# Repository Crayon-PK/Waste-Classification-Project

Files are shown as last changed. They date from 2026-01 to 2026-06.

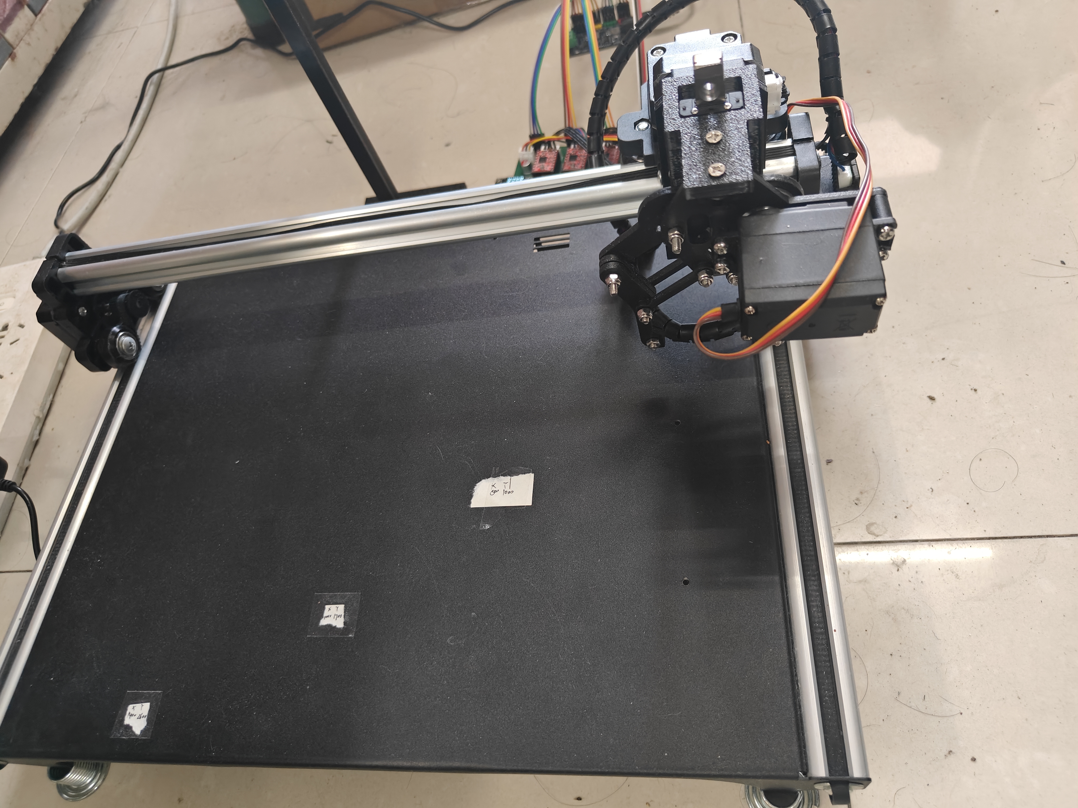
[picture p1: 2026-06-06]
picture/IMG20260606160438.jpg

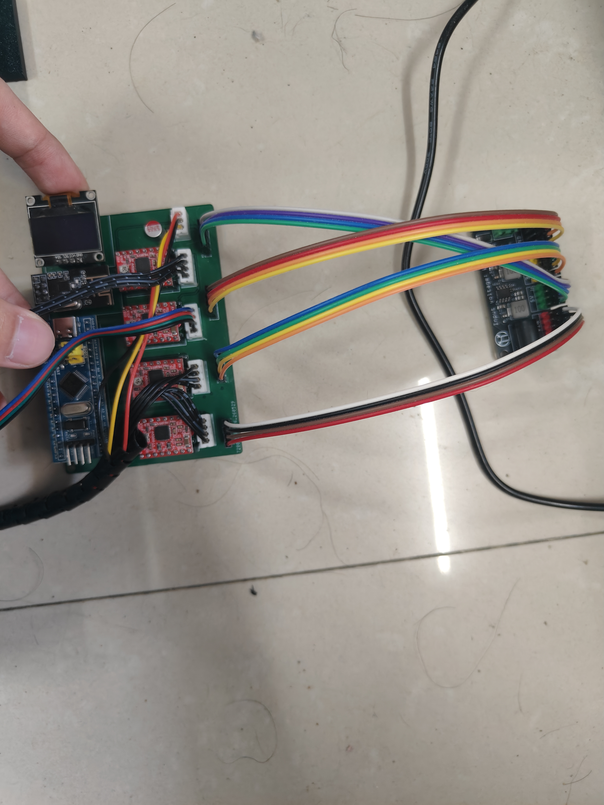
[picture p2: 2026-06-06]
picture/IMG20260606161021.jpg

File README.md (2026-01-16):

\# 智能垃圾分类系统 (Smart Waste Classification System)

本项目包含从机械结构、电路设计、嵌入式固件到上位机代码。

\## 📂 目录结构说明

\* \*\*Software\*\*: 上位机代码 (Python + YOLOv5-Lite)，负责视觉识别与串口通讯。

\* \*\*Firmware\*\*: 下位机固件 (STM32F103 + FreeRTOS)，负责处理上位机信息，控制步进电机、舵机与 OLED日志打印。

\* \*\*Hardware\*\*: PCB 工程文件 (立创EDA专业版格式)。

\* \*\*Mechanical\*\*: 3D 机械结构设计 (SolidWorks 源文件 + 打印用 STL)。

\## 🚀 快速上手

\### 1. 软件端 (Software)

\* \*\*环境\*\*: Python 3.8+, 安装依赖: `pip install -r Software/requirements.txt`

\* \*\*运行\*\*: 

&nbsp;   1. 连接 USB 摄像头和串口工具。

&nbsp;   2. 进入目录: `cd Software`

&nbsp;   3. 运行主程序: `python gui.py`

\* \*\*注意\*\*: 权重文件已包含在 `Software/weights/best2.pt`，无需额外下载。

\### 2. 固件端 (Firmware)

\* \*\*环境\*\*: Keil uVision 5 (MDK-ARM).

\* \*\*编译\*\*: 打开 `Firmware/MDK-ARM/Project.uvprojx`，点击 "Rebuild" 即可重新生成 Hex 文件。

\* \*\*烧录\*\*: 使用 ST-Link Utility 或 Keil 直接下载。

\### 3. 硬件与机械

\* \*\*PCB\*\*: 使用立创EDA专业版打开 `Hardware/PCB.eprj2`。

\* \*\*3D\*\*: 使用 SolidWorks 2020 或更高版本打开 `Mechanical` 文件夹内的 `.SLDASM` 装配体。

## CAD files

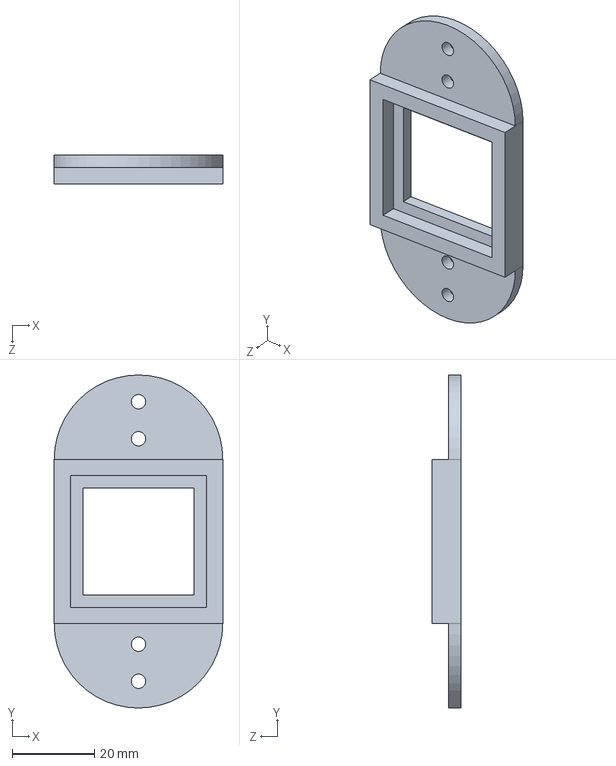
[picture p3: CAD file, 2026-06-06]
Mechanical/摄像头固定模块.SLDPRT
41.0 x 81.0 x 7.00 mm

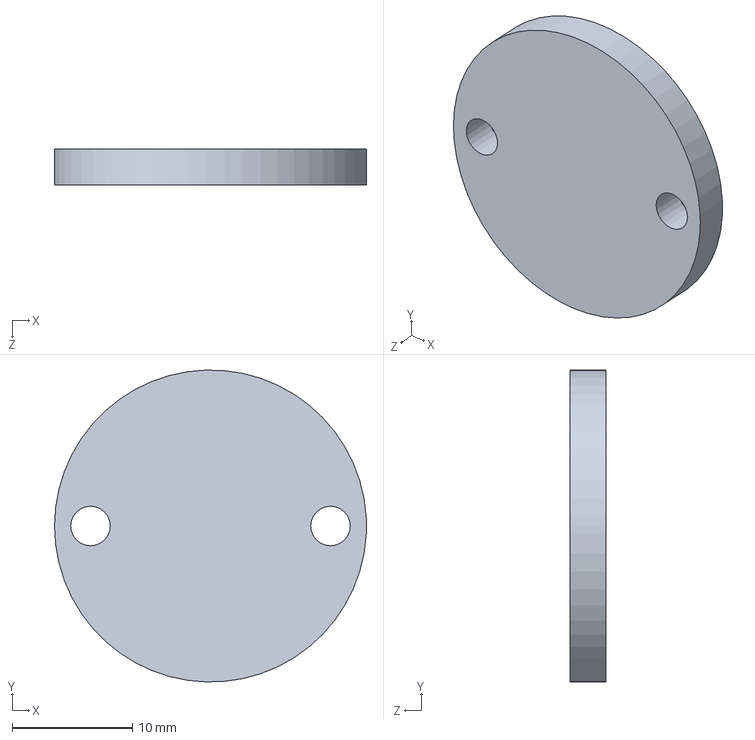
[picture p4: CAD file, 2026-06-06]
Mechanical/传动轴.SLDPRT
26.0 x 26.0 x 3.00 mm

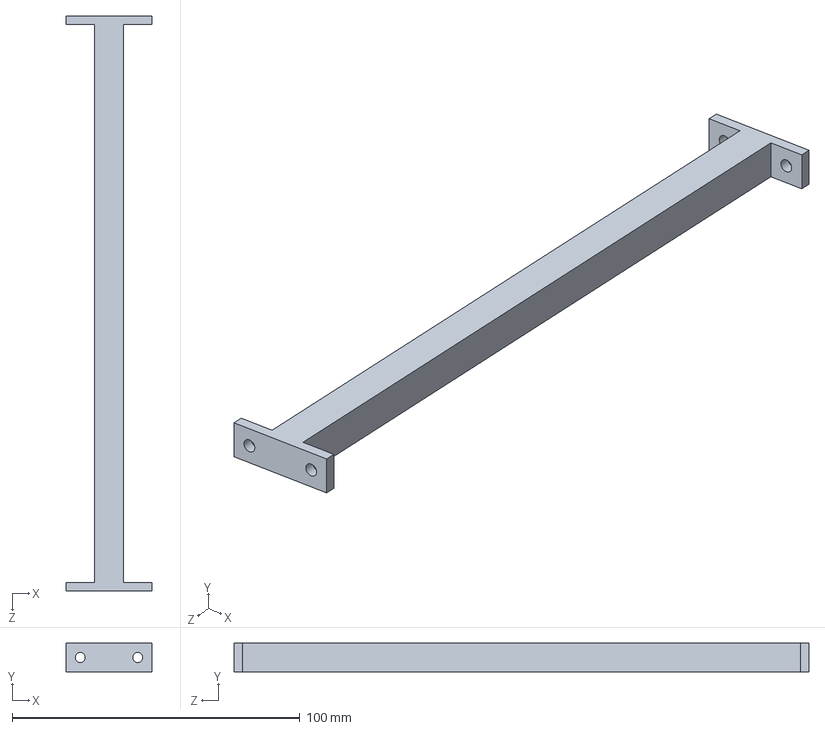
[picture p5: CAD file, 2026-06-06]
Mechanical/高度支架.SLDPRT
30.0 x 10.0 x 200.0 mm

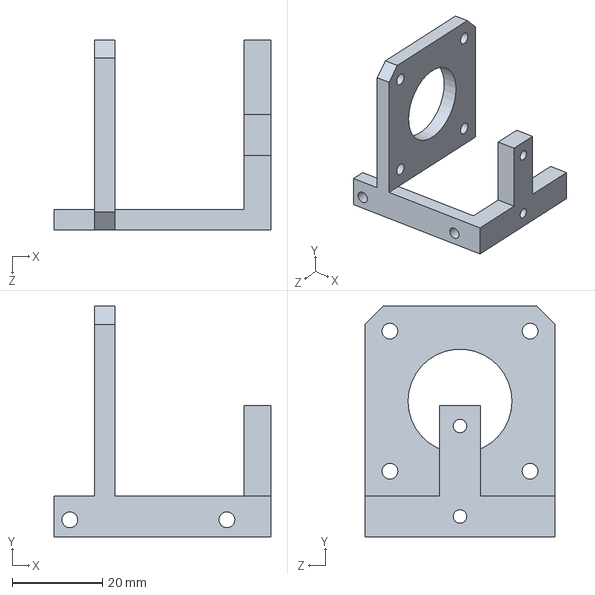
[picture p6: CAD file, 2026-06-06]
Mechanical/固定模块.SLDPRT
48.0 x 51.0 x 42.0 mm

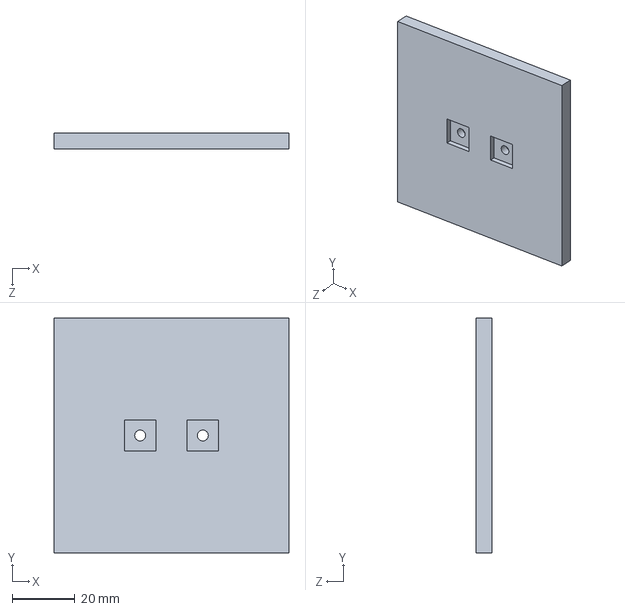
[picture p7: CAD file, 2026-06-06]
Mechanical/高度支架地基.SLDPRT
75.0 x 75.0 x 5.00 mm

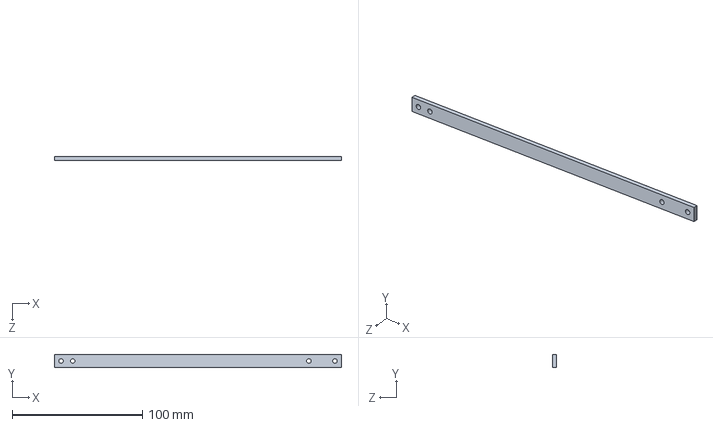
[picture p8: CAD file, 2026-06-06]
Mechanical/摄像头横向支架.SLDPRT
220.0 x 10.0 x 3.00 mm

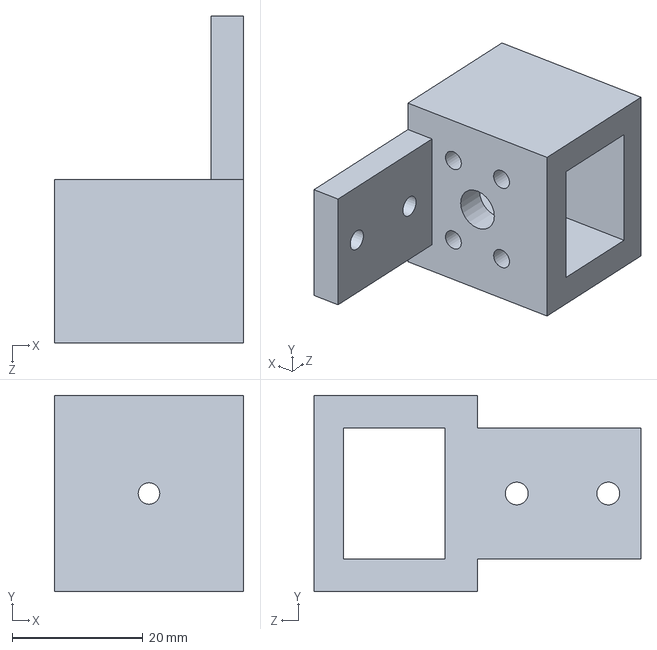
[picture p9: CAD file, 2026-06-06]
Mechanical/滑块夹爪固定装置.SLDPRT
28.9 x 30.0 x 50.0 mm

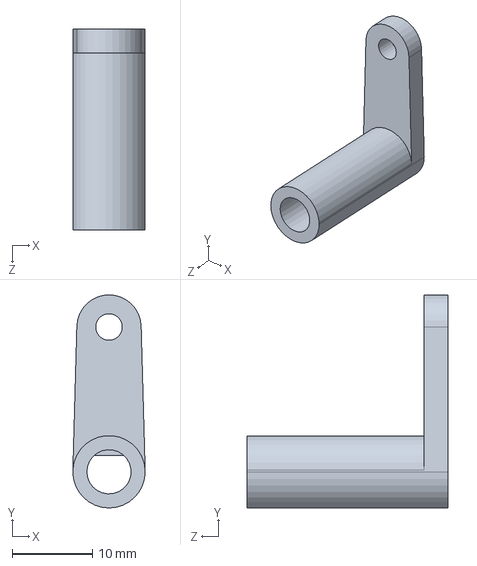
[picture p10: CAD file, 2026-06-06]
Mechanical/主动轴.SLDPRT
9.00 x 26.5 x 25.0 mm

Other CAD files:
Mechanical/STL/主动轴.STL
Mechanical/STL/传动轴.STL
Mechanical/STL/固定模块.STL
Mechanical/STL/摄像头固定模块.STL
Mechanical/STL/摄像头横向支架.STL
Mechanical/STL/滑块夹爪固定装置.STL
Mechanical/STL/高度支架.STL
Mechanical/STL/高度支架地基.STL

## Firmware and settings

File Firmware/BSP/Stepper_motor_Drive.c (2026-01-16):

#include "stm32f10x.h"
#include <stddef.h>

//================== 电机引脚定义 ==================
#define MOTOR_X_GPIO_PORT      GPIOB
#define MOTOR_X_STEP_PIN       GPIO_Pin_0     // PB0 - TIM3_CH3
#define MOTOR_X1_DIR_PIN       GPIO_Pin_12
#define MOTOR_X2_DIR_PIN       GPIO_Pin_13
#define MOTOR_X_EN_PIN         GPIO_Pin_14

#define MOTOR_Y_GPIO_PORT      GPIOA
#define MOTOR_Y_STEP_PIN       GPIO_Pin_3     // PA3 - TIM2_CH4
#define MOTOR_Y_DIR_PIN        GPIO_Pin_4
#define MOTOR_Y_EN_PIN         GPIO_Pin_5

#define MOTOR_Z_GPIO_PORT      GPIOB
#define MOTOR_Z_STEP_PIN       GPIO_Pin_9     // PB9 - TIM4_CH4
#define MOTOR_Z_DIR_PIN        GPIO_Pin_8
#define MOTOR_Z_EN_PIN         GPIO_Pin_5

//================ 电机相关参数 ==================
#define MOTOR_X 0
#define MOTOR_Y 1
#define MOTOR_Z 2

#define PWM_ARR 999
#define PWM_PSC 71

#define M_ENABLE  1
#define M_DISABLE 0

//================ 全局变量 ==================
volatile int32_t motor_pos_x = 0;
volatile int32_t motor_pos_y = 0;
volatile int32_t motor_pos_z = 0;

static volatile uint32_t step_count_x = 0, target_steps_x = 0;
static volatile uint32_t step_count_y = 0, target_steps_y = 0;
static volatile uint32_t step_count_z = 0, target_steps_z = 0;

static volatile uint8_t dir_x = 1, dir_y = 1, dir_z = 1;

typedef void (*Stepper_Callback_t)(uint8_t motor_id);
static Stepper_Callback_t cb_x = NULL;
static Stepper_Callback_t cb_y = NULL;
static Stepper_Callback_t cb_z = NULL;

void Stepper_RegisterCallback(uint8_t MotorID, Stepper_Callback_t cb)
{
    switch (MotorID)
    {
        case MOTOR_X: cb_x = cb; break;
        case MOTOR_Y: cb_y = cb; break;
        case MOTOR_Z: cb_z = cb; break;
    }
}
//-----------------------------------------------------------------GPIO引脚初始化-----------------------------------------------------------------
static void Motor_X_GPIO_Init(void)
{
    GPIO_InitTypeDef GPIO_InitStructure;

    RCC_APB2PeriphClockCmd(RCC_APB2Periph_GPIOB | RCC_APB2Periph_AFIO, ENABLE);

    // DIR & EN
    GPIO_InitStructure.GPIO_Pin = MOTOR_X1_DIR_PIN | MOTOR_X2_DIR_PIN | MOTOR_X_EN_PIN;
    GPIO_InitStructure.GPIO_Mode = GPIO_Mode_Out_PP;
    GPIO_InitStructure.GPIO_Speed = GPIO_Speed_50MHz;
    GPIO_Init(MOTOR_X_GPIO_PORT, &GPIO_InitStructure);

    // STEP (PWM output)
    GPIO_InitStructure.GPIO_Pin = MOTOR_X_STEP_PIN;
    GPIO_InitStructure.GPIO_Mode = GPIO_Mode_AF_PP;
    GPIO_Init(MOTOR_X_GPIO_PORT, &GPIO_InitStructure);

    // 默认状态：EN=高（禁用）
    GPIO_SetBits(MOTOR_X_GPIO_PORT, MOTOR_X_EN_PIN);
    GPIO_ResetBits(MOTOR_X_GPIO_PORT, MOTOR_X1_DIR_PIN);
    GPIO_SetBits(MOTOR_X_GPIO_PORT, MOTOR_X2_DIR_PIN);
}

static void Motor_Y_GPIO_Init(void)
{
    GPIO_InitTypeDef GPIO_InitStructure;

    RCC_APB2PeriphClockCmd(RCC_APB2Periph_GPIOA | RCC_APB2Periph_AFIO, ENABLE);

    // DIR & EN
    GPIO_InitStructure.GPIO_Pin = MOTOR_Y_DIR_PIN | MOTOR_Y_EN_PIN;
    GPIO_InitStructure.GPIO_Mode = GPIO_Mode_Out_PP;
    GPIO_InitStructure.GPIO_Speed = GPIO_Speed_50MHz;
    GPIO_Init(MOTOR_Y_GPIO_PORT, &GPIO_InitStructure);

    // STEP (PWM output)
    GPIO_InitStructure.GPIO_Pin = MOTOR_Y_STEP_PIN; // PA3 TIM2_CH4
    GPIO_InitStructure.GPIO_Mode = GPIO_Mode_AF_PP;
    GPIO_Init(MOTOR_Y_GPIO_PORT, &GPIO_InitStructure);

    GPIO_SetBits(MOTOR_Y_GPIO_PORT, MOTOR_Y_EN_PIN);
    GPIO_ResetBits(MOTOR_Y_GPIO_PORT, MOTOR_Y_DIR_PIN);
}

static void Motor_Z_GPIO_Init(void)
{
    GPIO_InitTypeDef GPIO_InitStructure;

    RCC_APB2PeriphClockCmd(RCC_APB2Periph_GPIOB | RCC_APB2Periph_AFIO, ENABLE);

    // DIR & EN
    GPIO_InitStructure.GPIO_Pin = MOTOR_Z_DIR_PIN | MOTOR_Z_EN_PIN;
    GPIO_InitStructure.GPIO_Mode = GPIO_Mode_Out_PP;
    GPIO_InitStructure.GPIO_Speed = GPIO_Speed_50MHz;
    GPIO_Init(MOTOR_Z_GPIO_PORT, &GPIO_InitStructure);

    // STEP (PWM output)
    GPIO_InitStructure.GPIO_Pin = MOTOR_Z_STEP_PIN;
    GPIO_InitStructure.GPIO_Mode = GPIO_Mode_AF_PP;
    GPIO_Init(MOTOR_Z_GPIO_PORT, &GPIO_InitStructure);

    GPIO_SetBits(MOTOR_Z_GPIO_PORT, MOTOR_Z_EN_PIN);
    GPIO_ResetBits(MOTOR_Z_GPIO_PORT, MOTOR_Z_DIR_PIN);
}

//-----------------------------------------------------------------PWM初始化-----------------------------------------------------------------
static void PWM_ChannelInit(TIM_TypeDef* TIMx, uint8_t channel, uint32_t arr, uint32_t psc)
{
    TIM_TimeBaseInitTypeDef TIM_TimeBaseStructure;
    TIM_OCInitTypeDef TIM_OCInitStructure;

    // 时基
    TIM_TimeBaseStructure.TIM_Period = (arr == 0) ? 1 : (arr - 1);
    TIM_TimeBaseStructure.TIM_Prescaler = (psc == 0) ? 0 : (psc - 1);
    TIM_TimeBaseStructure.TIM_ClockDivision = 0;
    TIM_TimeBaseStructure.TIM_CounterMode = TIM_CounterMode_Up;
    TIM_TimeBaseInit(TIMx, &TIM_TimeBaseStructure);

    // PWM 输出配置
    TIM_OCInitStructure.TIM_OCMode = TIM_OCMode_PWM1;
    TIM_OCInitStructure.TIM_OutputState = TIM_OutputState_Enable;
    TIM_OCInitStructure.TIM_Pulse = (TIMx->ARR + 1) / 2; // 默认 50% 占空比
    TIM_OCInitStructure.TIM_OCPolarity = TIM_OCPolarity_High;

    if (TIMx == TIM3 && channel == 3) {
        TIM_OC3Init(TIMx, &TIM_OCInitStructure);
        TIM_OC3PreloadConfig(TIMx, TIM_OCPreload_Enable);
    } else if (TIMx == TIM2 && channel == 4) {
        TIM_OC4Init(TIMx, &TIM_OCInitStructure);
        TIM_OC4PreloadConfig(TIMx, TIM_OCPreload_Enable);
    } else if (TIMx == TIM4 && channel == 4) {
        TIM_OC4Init(TIMx, &TIM_OCInitStructure);
        TIM_OC4PreloadConfig(TIMx, TIM_OCPreload_Enable);
    }

    TIM_ARRPreloadConfig(TIMx, ENABLE);
    // TIM_Cmd(TIMx, ENABLE); // 不立即启动，Step_Move 时启动
}


//==================== NVIC 初始化 ====================
static void Stepper_NVIC_Init(void)
{
    NVIC_InitTypeDef NVIC_InitStructure;

    // TIM3
    NVIC_InitStructure.NVIC_IRQChannel = TIM3_IRQn;
    NVIC_InitStructure.NVIC_IRQChannelPreemptionPriority = 12;
    NVIC_InitStructure.NVIC_IRQChannelSubPriority = 0;
    NVIC_InitStructure.NVIC_IRQChannelCmd = ENABLE;
    NVIC_Init(&NVIC_InitStructure);

    // TIM2
    NVIC_InitStructure.NVIC_IRQChannel = TIM2_IRQn;
    NVIC_InitStructure.NVIC_IRQChannelPreemptionPriority = 13;
    NVIC_InitStructure.NVIC_IRQChannelSubPriority = 0;
    NVIC_Init(&NVIC_InitStructure);

    // TIM4
    NVIC_InitStructure.NVIC_IRQChannel = TIM4_IRQn;
    NVIC_InitStructure.NVIC_IRQChannelPreemptionPriority = 14;
    NVIC_InitStructure.NVIC_IRQChannelSubPriority = 0;
    NVIC_Init(&NVIC_InitStructure);
}

//==================== 初始化所有电机 ====================
void Stepper_Init_All(void)
{
    Motor_X_GPIO_Init();
    Motor_Y_GPIO_Init();
    Motor_Z_GPIO_Init();

    // 开时钟
    RCC_APB1PeriphClockCmd(RCC_APB1Periph_TIM3 | RCC_APB1Periph_TIM2 | RCC_APB1Periph_TIM4, ENABLE);

    // 默认频率（小心：arr/psc 会在 SetFreq 时覆盖）
    PWM_ChannelInit(TIM3, 3, PWM_ARR, PWM_PSC);
    PWM_ChannelInit(TIM2, 4, PWM_ARR, PWM_PSC);
    PWM_ChannelInit(TIM4, 4, PWM_ARR, PWM_PSC);

    Stepper_NVIC_Init();
}
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

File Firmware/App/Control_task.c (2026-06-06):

#include "stm32f10x.h"
#include "FreeRTOS.h"
#include "task.h"
#include "semphr.h"
#include "event_groups.h"

#include "app_types.h"
#include "app_shared.h"
#include "Stepper_motor_Drive.h"
#include "servo.h"

// Control任务参数设置
#define CONTROL_TASK_PRIO       	3             // 优先级
#define CONTROL_TASK_STACK_SIZE 	512			  // 栈大小
static TaskHandle_t control_task_handle;

QueueHandle_t Control_StateQueue; // 控制状态队列

// 垃圾桶坐标定义 [X, Y]
uint16_t binPos_t[4][2] = 
{
    {2000,750},
    {2000,1500},
    {2000,2250},
    {2000,3000}
};

static NrfDataPacket_t local; 			// 本地控制数据副本 
static SystemStage_t stage = CTRL_IDLE; // 当前控制阶段

// 辅助函数：更新状态并发送到队列（通知OLED）
void Control_SetState(SystemStage_t new_state)
{
    uint8_t s = (uint8_t)new_state;
    xQueueOverwrite(Control_StateQueue, &s);
}

// 电机中断回调
static void stepper_isr_cb(uint8_t motor_id)
{
    BaseType_t xHigherPriorityTaskWoken = pdFALSE;
    switch (motor_id) {
        case MOTOR_X: xEventGroupSetBitsFromISR(g_controlEventGroup, EVT_X_DONE, &xHigherPriorityTaskWoken); break;
        case MOTOR_Y: xEventGroupSetBitsFromISR(g_controlEventGroup, EVT_Y_DONE, &xHigherPriorityTaskWoken); break;
        case MOTOR_Z: xEventGroupSetBitsFromISR(g_controlEventGroup, EVT_Z_DONE, &xHigherPriorityTaskWoken); break;
        default: break;
    }
    portYIELD_FROM_ISR(xHigherPriorityTaskWoken);
}

void control(void *pvParameters)
{
    EventBits_t wait_bits = 0; // 用于记录当前真正需要等待的标志位

    while (1)
    {
        if (stage == CTRL_IDLE)        // 等待新的数据包
        {
            if (shared_wait_control(portMAX_DELAY) == pdTRUE)
            {
                shared_copy_packet(&local);
                stage = CTRL_MOVE_XY;
            }
        }
        // 根据当前阶段推进
        switch (stage)
        {
            case CTRL_MOVE_XY:
				Control_SetState(stage); // 更新任务状态
				
				// --- 先移动Y轴并等待完成（防撞） ---
                if (local.posY != motor_pos_y)
                {
                    Stepper_Move(MOTOR_Y, local.posY);
                    xEventGroupWaitBits(g_controlEventGroup, EVT_Y_DONE, 
                                        pdTRUE, pdTRUE, portMAX_DELAY);
                }
				
                // --- 再移动X轴并等待完成 ---
                if (local.posX != motor_pos_x)
                {
                    Stepper_Move(MOTOR_X, local.posX);
                    xEventGroupWaitBits(g_controlEventGroup, EVT_X_DONE, 
                                        pdTRUE, pdTRUE, portMAX_DELAY);
                }
				
                // 等待 XY 两轴完成
				if (local.label == 0xFF)
                {
                    stage = CTRL_RELEASE; // 如果是复位，直接跳到释放阶段恢复舵机角度并结束
                    break;
                }
                stage = CTRL_MOVE_Z_DOWN;
                break;

            case CTRL_MOVE_Z_DOWN:
				Control_SetState(stage); // 更新任务状态
               // --- Z轴下放逻辑 ---
                if (local.posZ != motor_pos_z)
                {
                    Stepper_Move(MOTOR_Z, local.posZ);
                    // 等待 Z 完成
                    xEventGroupWaitBits(g_controlEventGroup, EVT_Z_DONE, 
                                        pdTRUE, pdTRUE, portMAX_DELAY);
                }
                stage = CTRL_GRAB;
                break;

            case CTRL_GRAB:
				Control_SetState(stage); // 更新任务状态
                Servo_SetAngle(local.angle);
                vTaskDelay(2000);
                stage = CTRL_MOVE_Z_UP;
                break;

            case CTRL_MOVE_Z_UP:
				Control_SetState(stage); // 更新任务状态
                if (motor_pos_z != 0) // 如果当前不在0点，才归零
                {
                    Stepper_Move(MOTOR_Z, 1);
                    xEventGroupWaitBits(g_controlEventGroup, EVT_Z_DONE, 
                                        pdTRUE, pdTRUE, portMAX_DELAY);
                }
                stage = CTRL_MOVE_TO_BIN;
                break;

            case CTRL_MOVE_TO_BIN:
			{
				Control_SetState(stage); // 更新任务状态
				
                uint8_t safe_idx = local.label - 1;	// 防止数组越界
				if (safe_idx > 3) safe_idx = 0; // 如果收到非法标签，默认去第1个桶，防止死机
				
                uint16_t binX = binPos_t[local.label - 1][0];
                uint16_t binY = binPos_t[local.label - 1][1];
                // --- X轴移动 ---
                if (binX != motor_pos_x)
                {
                    Stepper_Move(MOTOR_X, binX);
                    wait_bits |= EVT_X_DONE;
                }

                // --- Y轴移动 ---
                if (binY != motor_pos_y)
                {
                    Stepper_Move(MOTOR_Y, binY);
                    wait_bits |= EVT_Y_DONE;
                }

                // --- 等待 ---
                if (wait_bits != 0)
                {
                    xEventGroupWaitBits(g_controlEventGroup, wait_bits, 
                                        pdTRUE, pdTRUE, portMAX_DELAY);
                }
                stage = CTRL_RELEASE;
                break;
			}
            case CTRL_RELEASE:
				Control_SetState(stage); // 更新任务状态
                Servo_SetAngle(90);
                vTaskDelay(500);
			
                stage = CTRL_IDLE;  // 完成本包处理
				Control_SetState(stage); // 更新任务状态
				nrf_notify_tx();
                break;

            default:
                stage = CTRL_IDLE;
				Control_SetState(stage); // 更新任务状态
                break;
        }
    }
}


void Control_Task(void)
{
	// 确保队列只创建一次
    if (Control_StateQueue == NULL) {
        Control_StateQueue = xQueueCreate(1, sizeof(uint8_t));
    }
	
	xTaskCreate(control, "control", CONTROL_TASK_STACK_SIZE, NULL, CONTROL_TASK_PRIO, &control_task_handle);
	
	Stepper_RegisterCallback(MOTOR_X, stepper_isr_cb);
    Stepper_RegisterCallback(MOTOR_Y, stepper_isr_cb);
    Stepper_RegisterCallback(MOTOR_Z, stepper_isr_cb);
}

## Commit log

2026-01-16 Initial commit: Complete project upload (Source, PCB, CAD, and Models)
    [主动轴.SLDPRT, 主动轴.STL, 传动轴.SLDPRT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]
2026-01-16 Increase camera selection
2026-06-06 下位机核心逻辑不变，上位机增加了识别的像素坐标与真实电机步数之间的映射计算。pcb 1.0 采取全部插件，降低焊接强度简化维护难度，供电采取外部电源接入。机械设计通过购买滑轨来实现连杆运动，同时增加摄像头的固定模块，机械部分与实际产品强相关，无太大借鉴意义
    [主动轴.SLDPRT, 主动轴.STL, 传动轴.SLDPRT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]
2026-06-06 相关图片视频
